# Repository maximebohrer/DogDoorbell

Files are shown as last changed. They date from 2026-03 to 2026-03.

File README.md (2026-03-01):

Dog Doorbell
============

This project is a capacitive sensor with a buzzer designed to detect when a dog is at the door and signal the owners to open it. Useful if the dog stands against the door to get inside instead of barking. When the dog touches the sensor, the buzzer rings.

Demo video (https://www.youtube.com/watch?v=xSRR1j4SNbI)

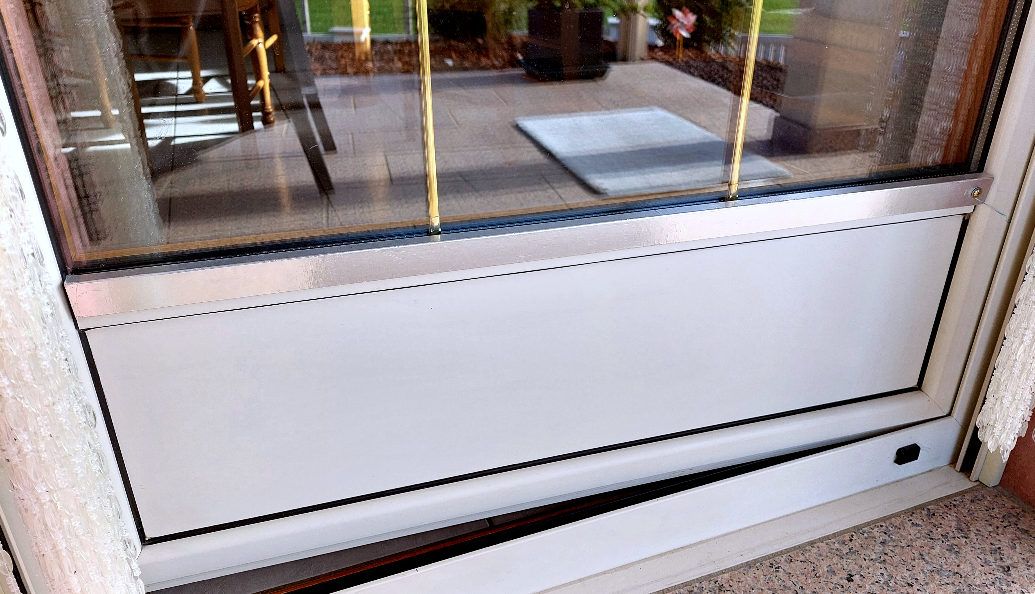
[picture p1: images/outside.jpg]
Outside (capacitive sensor)


Inside (electronics)

Working principle
-----------------

The sensor is simply a piece of metal. It forms a very low-value capacitor with respect to its environment. When the dog touches the sensor, it adds its own capacitance to the system.

This capacitance can easily be estimated by a microcontroller by applying a voltage to the sensor through a high-value resistor. This slowly charges the capacitor, causing the sensor’s voltage to rise. We then measure the time it takes for an input directly connected to the sensor to register a high level. The more mass that is touching the sensor, the greater the capacitance relative to the environment, and the longer it takes to charge the sensor.

This process is repeated multiple times per second, and the readings are averaged and filtered. When the microcontroller detects a sudden increase in capacitance (when the value exceeds the set sensitivity threshold), the buzzer plays a sound, indicating that the dog is touching the sensor and wants to come inside.

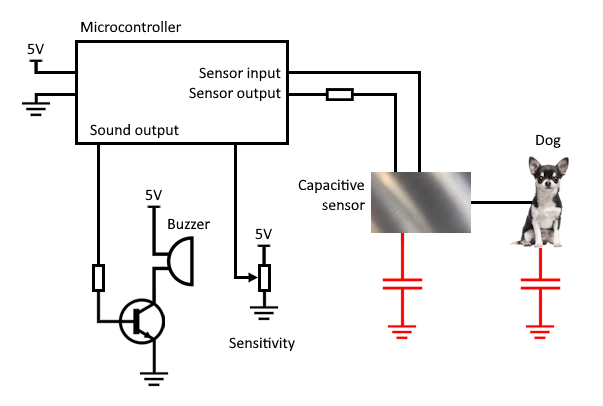
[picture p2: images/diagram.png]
Electrical diagram


Electronics are soldered by hand on a perfboard.

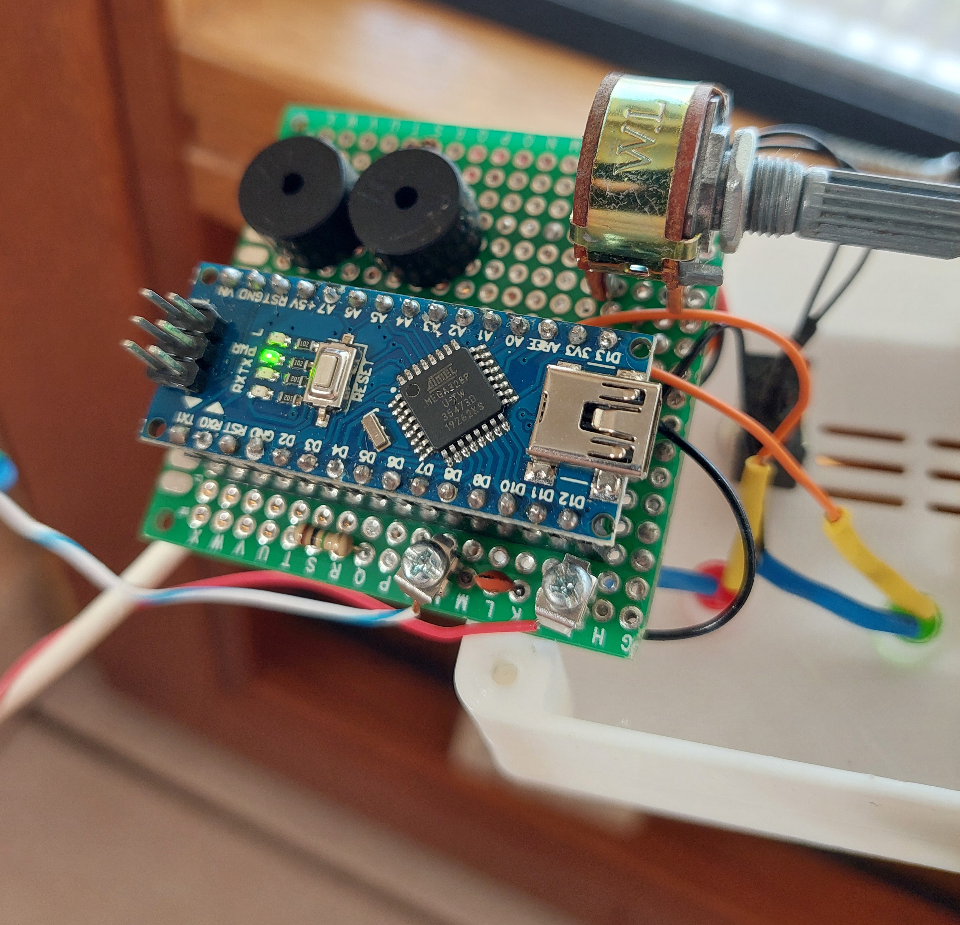
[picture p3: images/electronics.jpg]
Electronics


Programming
-----------

The microcontroller is an Arduino Nano programmed using the Arduino IDE.
It uses the [Tone library by bhagman](https://github.com/bhagman/Tone) to play tones on two pins simultaneously. 2 spare hardware timers are required for that. The default Arduino library only alows to play a tone on one pin at a time. Using two buzzers instead of one allows to create more interesting music.

3D models
---------

The case was designed to fit the door and was 3D-printed. It has holes for a switch, a potentiometer, two LEDs, two wires (power and sensor) and holes to let sound out. It holds the PCB in place when the two pieces are screwed together. The 3D models were created using Sketchup.

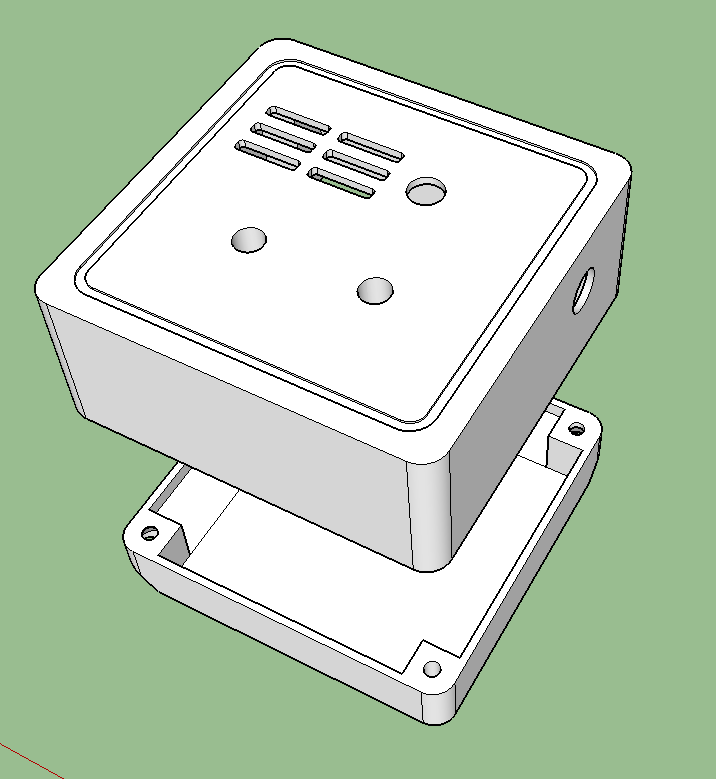
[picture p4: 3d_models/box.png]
Case 3D model


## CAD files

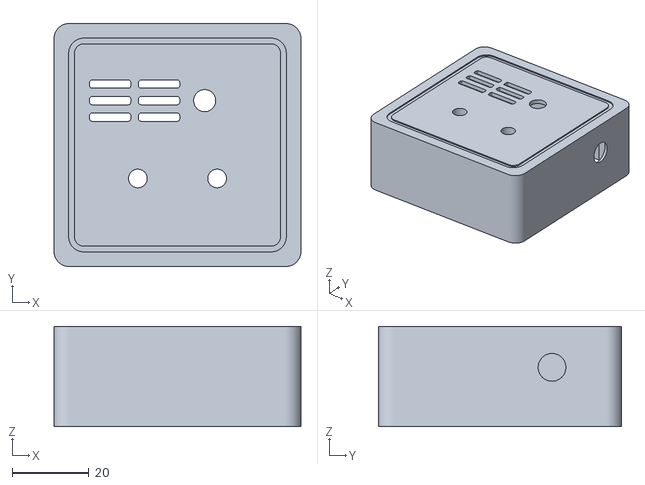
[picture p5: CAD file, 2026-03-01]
3d_models/box.stl
64.6 x 63.6 x 26.2

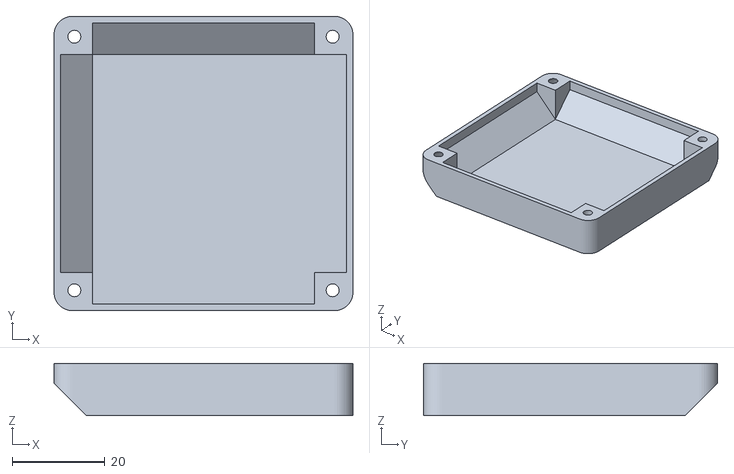
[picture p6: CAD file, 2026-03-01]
3d_models/lid.stl
64.6 x 63.6 x 11.3

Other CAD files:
3d_models/3d_models.skp

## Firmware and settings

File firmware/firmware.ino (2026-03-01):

#include <Tone.h> // https://github.com/bhagman/Tone
#include <EEPROM.h>

#define sensorIn 4 // In and out both on port D
#define sensorOut 2
#define buzzer1Pin 7
#define buzzer2Pin 8
#define ledPin 13
#define potPin A2

// Music notes frequency
const int C[] = {33, 65, 131, 262, 523, 1047, 2093, 418, 8372, 16744};
const int Cs[] = {35, 69, 139, 277, 554, 1109, 2217, 4435, 8870, 17740};
const int D[] = {37, 73, 147, 294, 587, 1175, 2349, 4699, 9397, 18795};
const int Ds[] = {39, 78, 156, 311, 622, 1245, 2489, 4978, 9956, 19912};
const int E[] = {42, 82, 165, 330, 659, 1319, 2637, 5274, 10548, 21096};
const int F[] = {44, 87, 175, 349, 698, 1397, 2794, 5588, 11175, 22351};
const int Fs[] = {46, 93, 185, 370, 740, 1480, 2960, 5920, 11840, 23680};
const int G[] = {49, 98, 196, 392, 784, 1568, 3134, 6272, 12544, 25088};
const int Gs[] = {52, 104, 208, 415, 831, 1661, 3322, 6645, 13290, 26580};
const int A[] = {55, 110, 220, 440, 880, 1760, 3520, 7040, 14080, 28160};
const int As[] = {58, 117, 233, 466, 932, 1865, 3729, 7459, 14917, 29834};
const int B[] = {62, 123, 247, 494, 988, 1976, 3951, 7902, 15804, 31609};

float baselineToSubtract;
float filteredMeasurement;
bool detection = 0;
const long timeout = 500000;
float threshold;

// Sampling
const int samplingPeriod = 50;
unsigned long samplingTimer = 0;

// Music and LED
unsigned long ledTimer = 0;
bool ledState = 0;
Tone buzzer1;
Tone buzzer2;

class Music {
  private:
  // Buzzer 1
    int* notes1;        // Frequency of the notes that have to be played. 0 if no sound
    int* noteLengths1;  // How many units of time each notes have to be played (Same length as notes1)
    int quantity1;      // Number of notes in the melody (Length of notes1 and noteLengths1 arrays)
    int index1;         // Keeps track of what note is being played in the notes1 array
    int subindex1;      // Keeps track of how many units of time of this note have already been played

    // Buzzer 2
    int* notes2;
    int* noteLengths2;
    int quantity2;
    int index2;
    int subindex2;

    int interval;    // Length of the unit of time in milliseconds
    unsigned long musicTimer;

    bool playing;

  public:
    Music(int notes1[], int noteLengths1[], int quantity1, int notes2[], int noteLengths2[], int quantity2, int interval) {
      this->notes1 = notes1;
      this->noteLengths1 = noteLengths1;
      this->quantity1 = quantity1;
      this->notes2 = notes2;
      this->noteLengths2 = noteLengths2;
      this->quantity2 = quantity2;
      this->interval = interval;

      playing = false;
      index1 = 0;
      subindex1 = 0;
      index2 = 0;
      subindex2 = 0;
    }

    void play() {
      if (millis() - musicTimer >= interval || !playing) {
        musicTimer = millis();

        if (notes1[index1] > 0 && (subindex1 == 0 || !playing)) { // Call play() only if it's a new note or if the music is resumed (The Tone library handles the timing by itself)
          buzzer1.play(notes1[index1], (noteLengths1[index1] - subindex1) * interval - interval / 10); // Subtract a tenth of time unit to have a clear gap between notes
        }
        if (notes2[index2] > 0 && (subindex2 == 0 || !playing)) {
          buzzer2.play(notes2[index2], (noteLengths2[index2] - subindex2) * interval - interval / 10);
        }

        subindex1++;
        if (subindex1 >= noteLengths1[index1]) {
          index1++;
          subindex1 = 0;
          if (index1 >= quantity1) {
            index1 = 0;
          }
        }
        subindex2++;
        if (subindex2 >= noteLengths2[index2]) {
          index2++;
          subindex2 = 0;
          if (index2 >= quantity2) {
            index2 = 0;
          }
        }

        playing = true;
      }
    }

    void stop() {
      playing = false;
      buzzer1.stop();
      buzzer2.stop();
    }
};

Music *currentMusic; // Pointer to the current music

// Comptine d'un autre été
const int amelie_notes1[] =     { E[2], B[2], G[2], B[2], E[2], B[2], G[2], B[2],    D[2], B[2], G[2], B[2], D[2], B[2], G[2], B[2],    D[2], B[2], Fs[2], B[2], D[2], B[2], Fs[2], B[2],    D[2], A[2], Fs[2], A[2], D[2], A[2], Fs[2], A[2]};
const int amelie_noteLengths1[] = { 2,    2,    2,    2,    2,    2,    2,    2,       2,    2,    2,    2,    2,    2,    2,    2,       2,    2,    2,     2,    2,    2,    2,     2,       2,    2,    2,     2,    2,    2,    2,     2};
const int amelie_notes2[] =     { B[3], E[4], B[4], B[3], E[4], B[4], B[3], E[4], B[4], B[3], E[4], B[4], B[3], E[4], C[4], E[4],    B[3], D[4], B[4], B[3], D[4], B[4], B[3], D[4], B[4], B[3], D[4], B[4], B[3], D[4], A[3], D[4],    Fs[3], B[3], Fs[4], Fs[3], B[3], Fs[4], Fs[3], B[3], Fs[4], Fs[3], B[3], Fs[4], Fs[3], B[3], G[3], B[3],    A[3], D[4], A[4], A[3], D[4], A[4], A[3], D[4], A[4], A[3], D[4], A[4], A[3], D[4], G[3], D[4]};
const int amelie_noteLengths2[] = { 1,    1,    1,    1,    1,    1,    1,    1,    1,    1,    1,    1,    1,    1,    1,    1,       1,    1,    1,    1,    1,    1,    1,    1,    1,    1,    1,    1,    1,    1,    1,    1,       1,     1,    1,     1,     1,    1,     1,     1,    1,     1,     1,    1,     1,     1,    1,    1,       1,    1,    1,    1,    1,    1,    1,    1,    1,    1,    1,    1,    1,    1,    1,    1};
Music amelie(amelie_notes1, amelie_noteLengths1, 32, amelie_notes2, amelie_noteLengths2, 64, 230);

// Canon in D
const int canon_notes1[] =     { D[2], A[2], D[3], A[2], A[1], E[2], A[2], E[2], B[1], Fs[2], B[2], Fs[2], Fs[1], Cs[2], Fs[2], Cs[2], G[1], D[2], G[2], D[2], D[2], A[2], D[3], A[2], G[1], D[2], G[2], D[2], A[1], E[2], A[2], E[2] };
const int canon_noteLengths1[] = { 2,    2,    2,    2,    2,    2,    2,    2,    2,    2,     2,    2,     2,     2,     2,     2,     2,    2,    2,    2,    2,    2,    2,    2,    2,    2,    2,    2,    2,    2,    2,    2 };
const int canon_notes2[] =     { A[4], Fs[4], G[4], A[4], Fs[4], G[4], A[4], A[3], B[3], Cs[4], D[4], E[4], Fs[4], G[4], Fs[4], D[4], E[4], Fs[4], Fs[3], G[3], A[3], B[3], A[3], G[3], A[3], D[4], Cs[4], D[4], B[3], D[4], Cs[4], B[3], A[3], G[3], A[3], G[3], Fs[3], G[3], A[3], B[3], Cs[4], D[4], B[3], D[4], Cs[4], B[3], Cs[4], D[4], E[4], A[3], B[3], Cs[4], D[4], E[4], Fs[4], G[4] };
const int canon_noteLengths2[] = { 2,    1,     1,    2,    1,     1,    1,    1,    1,    1,     1,    1,    1,     1,    2,     1,    1,    2,     1,     1,    1,    1,    1,    1,    1,    1,    1,     1,    2,    1,    1,     2,    1,    1,    1,    1,    1,     1,    1,    1,    1,     1,    2,    1,    1,     2,    1,     1,    1,    1,    1,    1,     1,    1,    1,     1};
Music canon(canon_notes1, canon_noteLengths1, 32, canon_notes2, canon_noteLengths2, 56, 200);

// Still DRE
const int dre_notes1[] =     { A[2], 0,  B[2], E[2], 0,   E[2]};
const int dre_noteLengths1[] = { 12,   24, 12,   12,   24,  12};
const int dre_notes2[] =     { A[4], 0, C[4], E[4], A[4], 0, C[4], E[4], A[4], 0, C[4], E[4], A[4], 0, C[4], E[4], A[4], 0, C[4], E[4], A[4], 0, C[4], E[4], A[4], 0, C[4], E[4], A[4], 0,    B[3], E[4], A[4], 0, B[3], E[4], A[4], 0, B[3], E[4], A[4], 0,    B[3], E[4], G[4], 0, B[3], E[4], G[4], 0, B[3], E[4], G[4], 0, B[3], E[4], G[4], 0, B[3], E[4], G[4], 0,    C[4], E[4]};
const int dre_noteLengths2[] = { 3,    1, 1,    1,    3,    1, 1,    1,    3,    1, 1,    1,    3,    1, 1,    1,    3,    1, 1,    1,    3,    1, 1,    1,    3,    1, 1,    1,    3,    1,    1,    1,    3,    1, 1,    1,    3,    1, 1,    1,    3,    1,    1,    1,    3,    1, 1,    1,    3,    1, 1,    1,    3,    1, 1,    1,    3,    1, 1,    1,    3,    1,    1,    1 };
Music dre(dre_notes1, dre_noteLengths1, 6, dre_notes2, dre_noteLengths2, 64, 53);

void setup() {
  pinMode(sensorIn, INPUT);
  pinMode(sensorOut, OUTPUT);
  pinMode(ledPin, OUTPUT);

  buzzer1.begin(buzzer1Pin);
  buzzer2.begin(buzzer2Pin);

  // Read potentiometer to set sensitivity
  threshold = map(analogRead(potPin), 0, 1023, 0, 5000);

  nextMusic();
  calibration();
  startupSound();
}

void nextMusic() {
  byte id = EEPROM.read(7); // Current music stored in address 7
  id = (id + 1) % 3; // Only 3 songs
  EEPROM.write(7, id);
  switch (id) {
    case 0:
      currentMusic = &amelie;
      break;
    case 1:
      currentMusic = &canon;
      break;
    case 2:
      currentMusic = &dre;
      break;
  }
}

void calibration() {
  baselineToSubtract = 0;
  int nb = 0;
  // Make 40 measurements and take average to find the baseline
  while (nb < 40) {
    if (millis() - samplingTimer >= samplingPeriod) {
      samplingTimer = millis();
      long measurement = takeMeasurement();
      if (measurement >= 0) {
        nb += 1;
        baselineToSubtract += measurement;
      }
    }
    // Blink led at the same time
    if (millis() - ledTimer >= 250) {
      ledTimer = millis();
      ledState = !ledState;
      digitalWrite(ledPin, ledState);
    }
  }
  baselineToSubtract /= 40.0;
  filteredMeasurement = 0;
  ledState = 0;
  digitalWrite(ledPin, LOW);
}

void startupSound() {
  buzzer1.play(Ds[5], 345);
  buzzer2.play(Gs[2], 798);
  delay(370);
  buzzer1.play(Ds[4], 132);
  delay(132);
  buzzer1.play(As[4], 271);
  delay(296);
  buzzer1.play(Gs[4], 345);
  buzzer2.play(C[3], 798);
  delay(370);
  buzzer1.play(Ds[4], 132);
  delay(132);
  buzzer1.play(Ds[5], 271);
  delay(296);
  buzzer1.play(As[4], 1000);
  buzzer2.play(Ds[2], 1000);
  delay(1000);
}

void loop() {
  if (millis() - samplingTimer >= samplingPeriod) {
    samplingTimer = millis();
    long measurement = takeMeasurement();
    if (measurement >= 0) {
      filteredMeasurement = (5.0 * filteredMeasurement + measurement - baselineToSubtract) / 6.0; // Subtract baseline and apply low pass filter
      if (!detection && filteredMeasurement >= threshold) {
        // Dog is here
        detection = 1;
      }
      else if (detection && filteredMeasurement < threshold) {
        // Dog is not here
        detection = 0;
        ledState = 0;
        digitalWrite(ledPin, LOW);
        currentMusic->stop();
      }

      if (!detection) baselineToSubtract = (63.0 * baselineToSubtract + measurement) / 64.0; // Adjust baseline dynamically to avoid false positives (very slow low pass filter)
    }
  }

  if (detection) {
    currentMusic->play(); // Play music
    // Blink led
    if (millis() - ledTimer >= 150) {
      ledTimer = millis();
      ledState = !ledState;
      digitalWrite(ledPin, ledState);
    }
  }
}

// measurement le temps de chargement/déchargement du capteur 10 fois. -1 si timeout
long takeMeasurement() {
  long total = 0;
  for (int i = 0; i < 10; i++) {
    long measurement = 0;

    // Here we disable interrupts to not mess up timing during critical measurement steps.
    // We directly write to PORTD to avoid the overhead of the Arduino functions (digitalWrite, pinMode, etc).
    noInterrupts();
    bitSet(PORTD, sensorOut);   // Output pin LOW just in case
    bitSet(DDRD, sensorIn);     // Set input pin as OUTPUT
    bitClear(PORTD, sensorIn);  // Input pin LOW to fully discharge the capacitive sensor
    delayMicroseconds(10);      // Wait for the sensor to discharge
    bitClear(DDRD, sensorIn);   // Input pin back as INPUT
    bitSet(PORTD, sensorOut);   // Output pin HIGH to charge the sensor through the resistor
    interrupts();

    while (!bitRead(PIND, sensorIn) && measurement < timeout) { // measurement of charge time
      measurement++;
    }

    noInterrupts();
    bitSet(DDRD, sensorIn);     // Input pin as OUTPUT
    bitSet(PORTD, sensorIn);    // Input pin HIGH to fully charge the capacitive sensor
    delayMicroseconds(10);      // Wait for the sensor to charge
    bitClear(DDRD, sensorIn);   // Input pin back as INPUT
    bitClear(PORTD, sensorIn);  // Input pin LOW to prepare next cycle and deactivate pullup resistor
    bitClear(PORTD, sensorOut); // Ouput pin LOW to discharge the sensor through the resistor
    interrupts();

    while (bitRead(PIND, sensorIn) && measurement < timeout) { // measurement of charge discharge time
      measurement++;
    }

    if (measurement >= timeout) {
      return -1;
    }
    total += measurement;
  }

  return total;
}
